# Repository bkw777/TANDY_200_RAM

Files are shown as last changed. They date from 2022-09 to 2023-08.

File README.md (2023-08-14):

# Option RAM module for TANDY 200

Replacements for TANDY 26-3866 24K SRAM module for TANDY 200 portable computer.

There are a few different options here. You pick whichever you need.  
* Single-bank, SOP-28 chip - Drop-in replacement for the original 24K module, with a large-ish chip that's relatively easy to solder by hand. Use this if you already have one original ceramic module, and want to keep using it, and just want one more 24K module to fill the machine, and you prefer to use, or happen to already have an SOIC-28/SOP-28 version of the SRAM chip.
* Single-bank, TSOP-28 chip - Same as above but uses a TSOP version of the SRAM chip.
* Dual-bank, SOP-32 chip - This provides the full 48 as 2 normal 24K modules all on one board. You plug a single one of these into OPTION RAM#2 slot. Uses an SOIC-32/SOP-32 chip for easier hand soldering.
* Dual-bank, TSOP-32 chip - Same as above but uses a TSOP version of the SRAM chip. These are more common and more available, but also more of a challenge to solder by hand.

The holes for the pins are intentionally too small to accept common square or round pins, as they are too fat and damage the leaf-style sockets in the 200. The BOMs include a specific pin that is extra thin, almost as thin as a dip chip leg. You may also use a SIL leadframe that has flat pins exactly like a DIP chip leg. See this [dip pcb legs guide](https://gist.github.com/bkw777/52d85d89eeff8445cc667685d05ea94d) for more details and links.

<!--
There are a few different designs available that all do the same thing but using different parts.

Some variants are single-bank like the original TANDY 26-3866 ceramic 24k module. These are drop-in replacements for the original modules, where one board = one bank = one Option RAM socket. You can have up to two boards installed in the machine.

Some variants are dual-bank, where one board supplies both Option RAM bank #1 and #2. You plug the one board into the Option RAM #2 socket, and this takes the place of two single-bank modules.

Some variants use different chip packages, so that you have options to use whatever types of chip you have, or can get, or can solder by hand.

There is also a [schematic of the original RAM bank](TANDY_26-3866.svg), re-drawn in KiCAD just for reference. There is no PCB for this, it's just for reference while designing new replacement modules to help ensure the replacement really still outwardly works the same as the original.
-->

See the [releases](../../releases) tab for gerber zips for manufacturing.  
If there is no link to order a pcb for one of the versions below, it means that design isn't tested and proven yet.

## Single-Bank - SOP

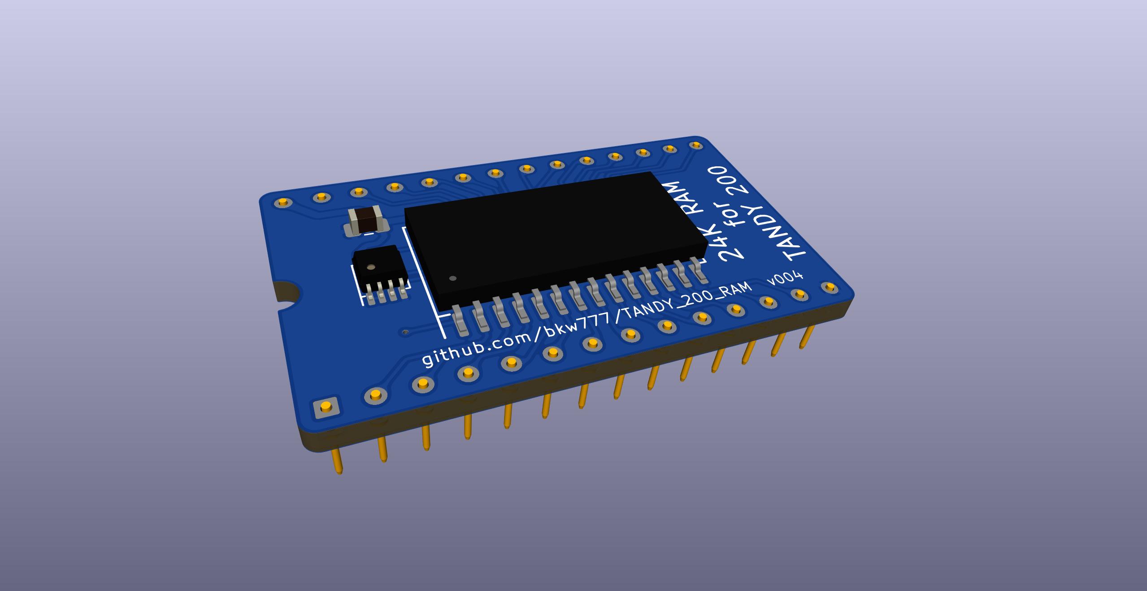
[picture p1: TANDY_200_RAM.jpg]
  
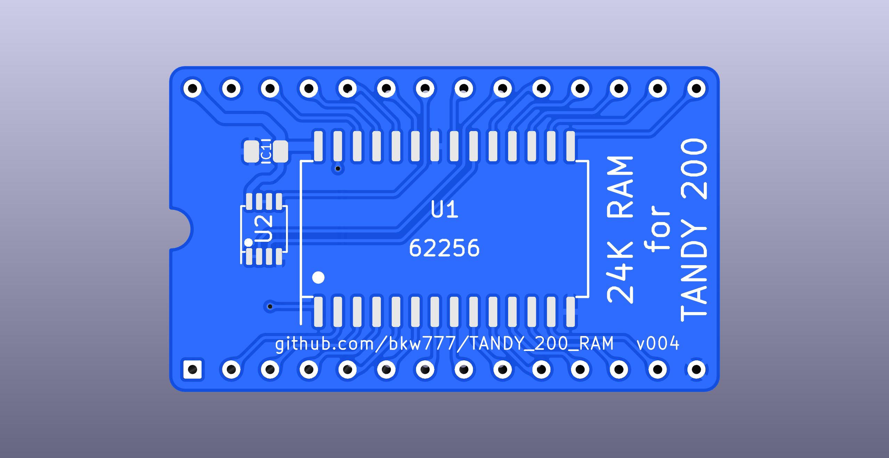
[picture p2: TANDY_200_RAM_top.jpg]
  
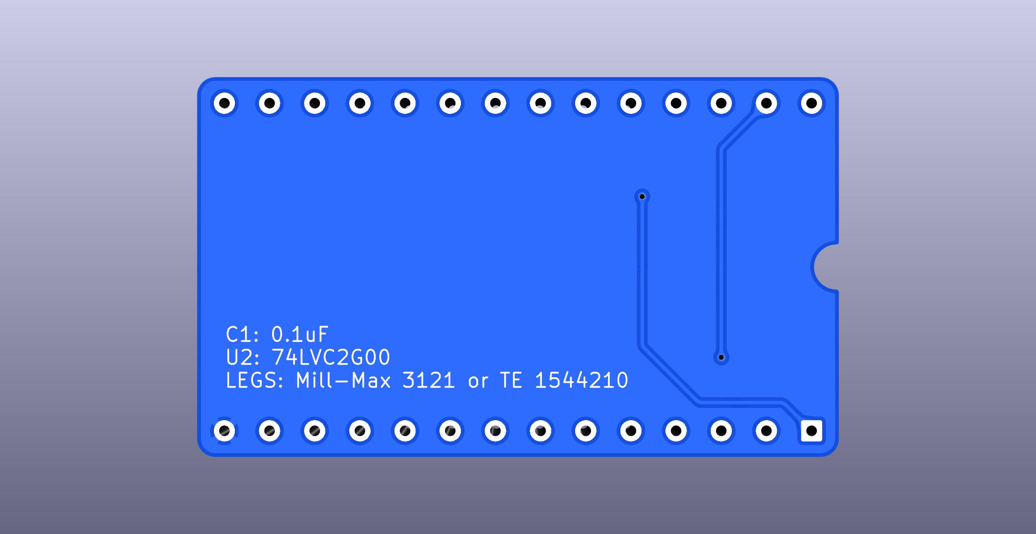
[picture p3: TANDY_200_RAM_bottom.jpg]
  
  

<!-- PCB from [OSHPark](),  or  [PCBWAY](),  or  [gerbers](../../releases/latest/)  -->
BOM from [DigiKey](https://www.digikey.com/short/f5hhwt4j),  or  [TANDY_200_RAM.BOM.csv](TANDY_200_RAM.BOM.csv)  

## Single-Bank - TSOP

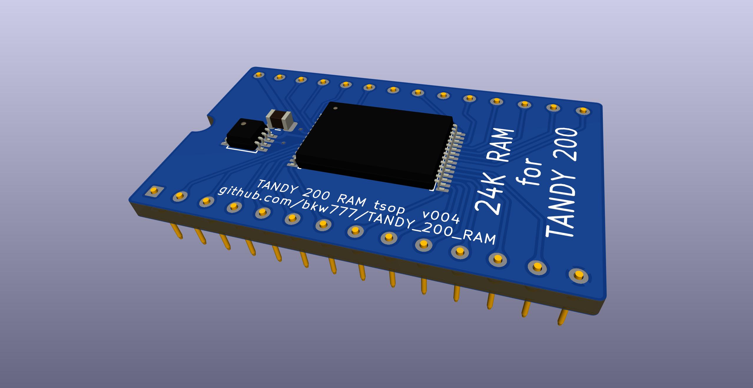
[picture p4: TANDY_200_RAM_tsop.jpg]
  
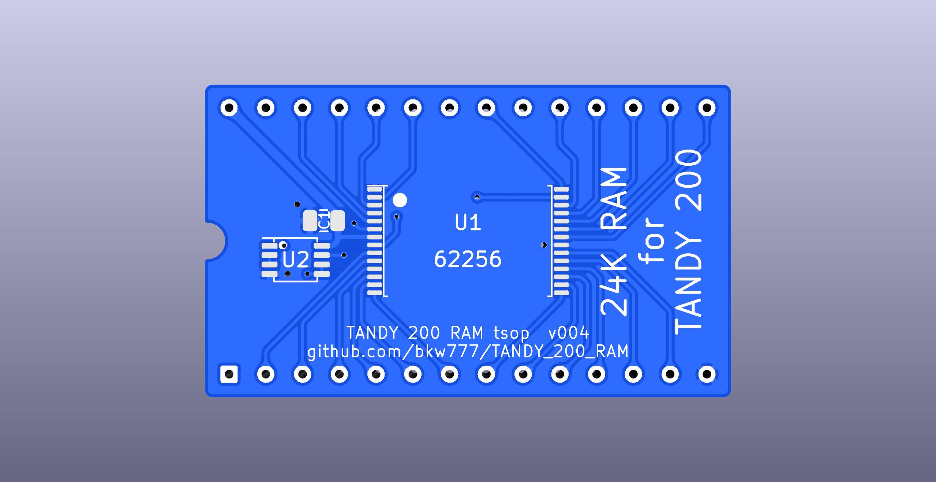
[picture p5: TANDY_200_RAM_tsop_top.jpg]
  
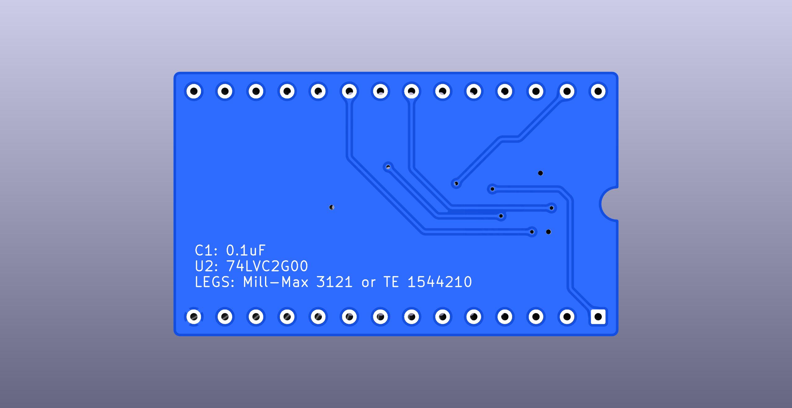
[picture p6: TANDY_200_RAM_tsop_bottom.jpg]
  

<!-- ![](../../raw/main/TANDY_200_RAM_tsop.svg)   -->

<!--
PCB from [OSHPark](),  or  [PCBWAY](),  or  [gerbers](../../releases/latest)  
BOM from [DigiKey](),  or  [BOM.csv]()  
-->

<!--
## Single-Bank THT DIP

![](../../raw/main/TANDY_200_RAM_tht.jpg)  
![](../../raw/main/TANDY_200_RAM_tht_top.jpg)  
![](../../raw/main/TANDY_200_RAM_tht_bottom.jpg)  
![](../../raw/main/TANDY_200_RAM_tht.svg)  

PCB from [OSHPark](),  or  [PCBWAY](),  or  [gerbers](../../releases/latest)  
BOM from [DigiKey](),  or  [BOM.csv]()  
-->

## Dual-Bank - SOP

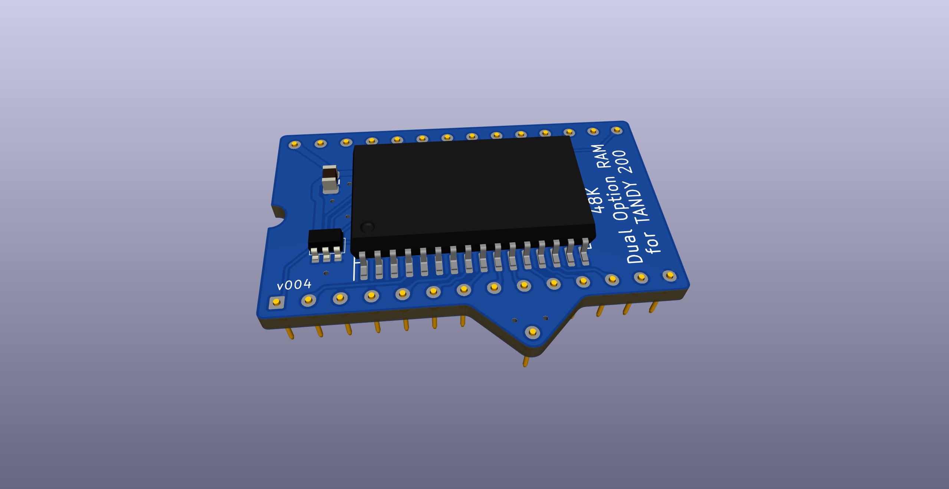
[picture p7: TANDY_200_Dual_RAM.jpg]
  
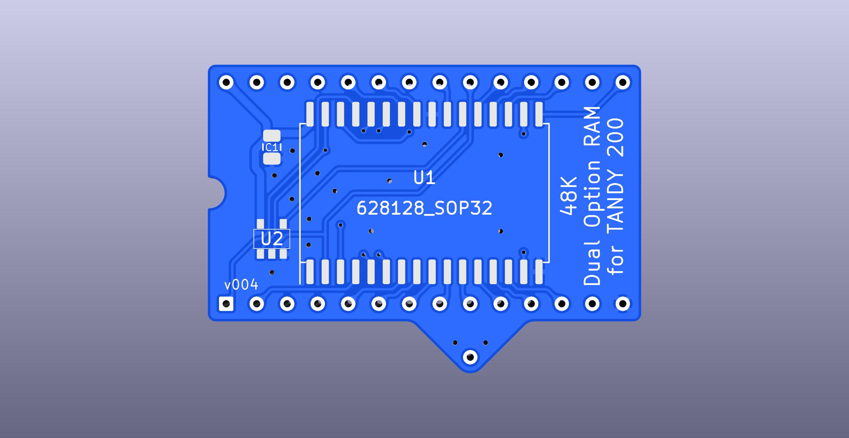
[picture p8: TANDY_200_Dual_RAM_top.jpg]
  
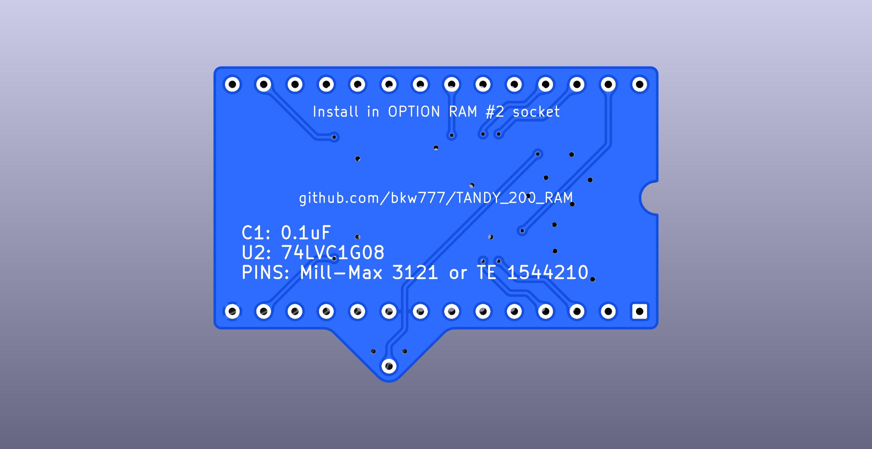
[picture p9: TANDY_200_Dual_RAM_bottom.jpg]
  
  

<!-- PCB from [OSHPark](),  or  [PCBWAY](),  or  [gerbers](../../releases/latest/)  -->  
BOM from [DigiKey](https://www.digikey.com/short/25v45c90),  or  [TANDY_200_Dual_RAM.BOM.csv](TANDY_200_Dual_RAM.BOM.csv)  

## Dual-Bank - TSOP

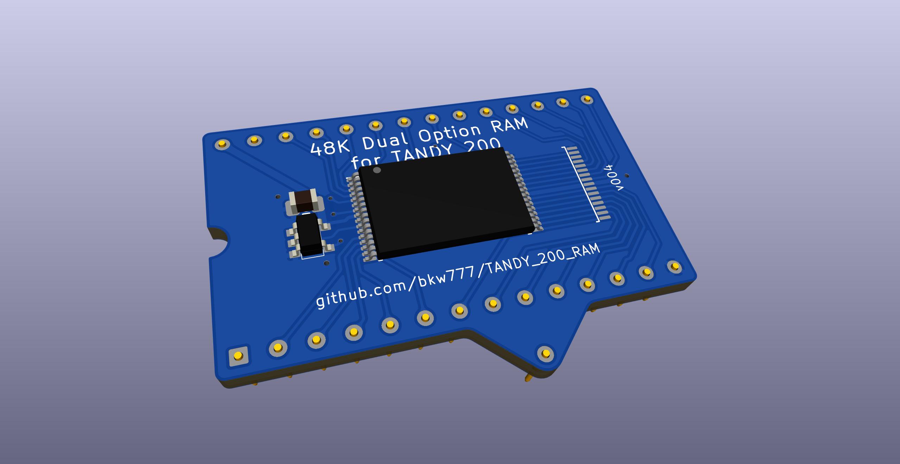
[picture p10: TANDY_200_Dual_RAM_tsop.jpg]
  
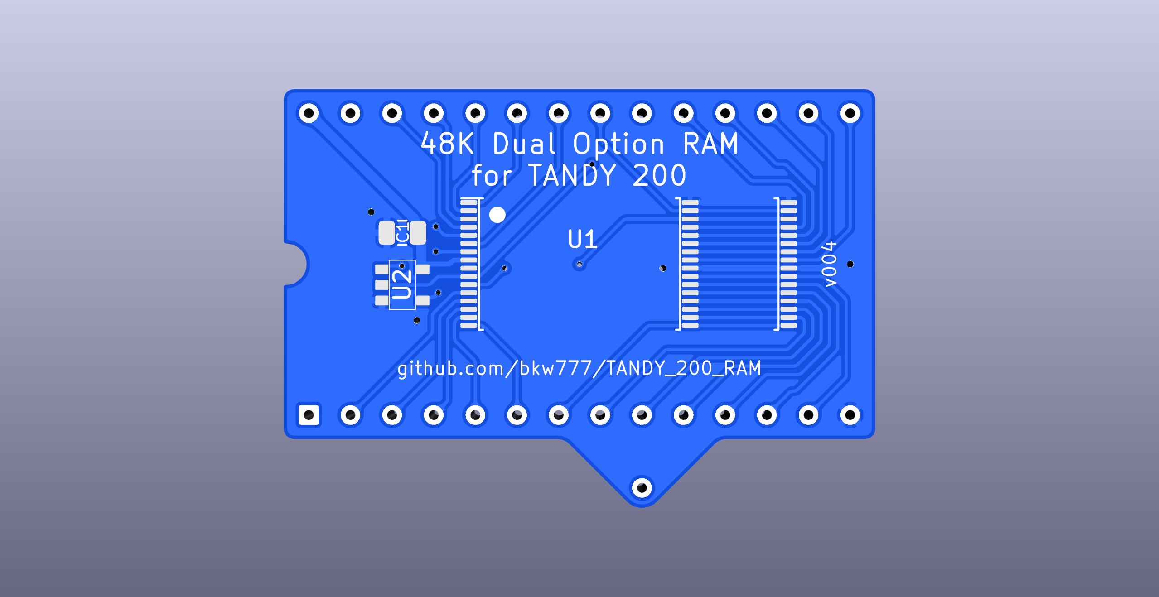
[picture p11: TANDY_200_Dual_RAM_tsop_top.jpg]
  
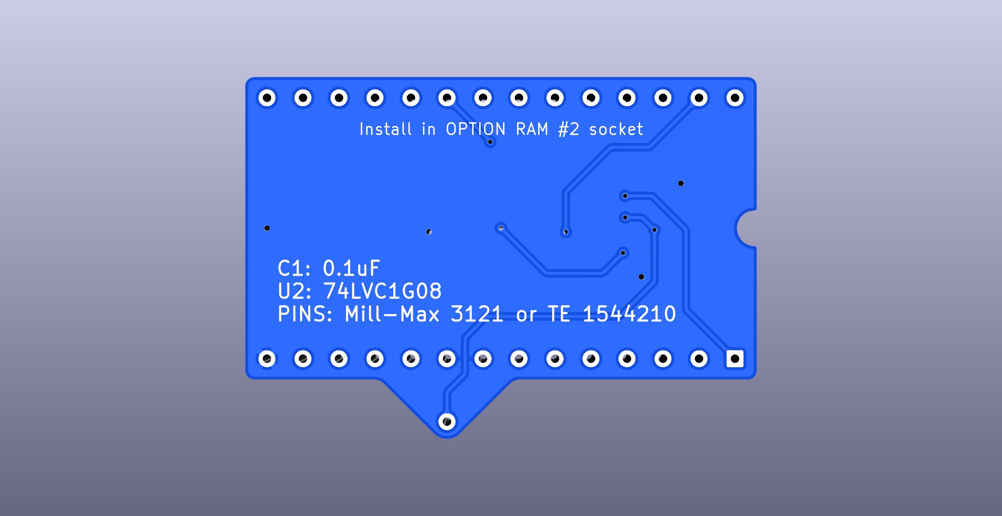
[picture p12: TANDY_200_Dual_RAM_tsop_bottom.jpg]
  
  

Supports both TSOP-32 (20mm) and sTSOP-32 (14mm).  

PCB from <!-- [OSHPark](),  or  -->[PCBWAY](https://www.pcbway.com/project/shareproject/TANDY_200_RAM_48K_TSOP_57aa6fd6.html),  or  [gerbers](../../releases/latest)  
BOM from [DigiKey](https://www.digikey.com/short/bvrwht5d),  or  [TANDY_200_Dual_RAM_tsop.BOM.csv](TANDY_200_Dual_RAM_tsop.BOM.csv)  

<!--
## Dual-Bank THT DIP

![](../../raw/main/TANDY_200_Dual_RAM_tht.jpg)  
![](../../raw/main/TANDY_200_Dual_RAM_tht_top.jpg)  
![](../../raw/main/TANDY_200_Dual_RAM_tht_bottom.jpg)  
![](../../raw/main/TANDY_200_Dual_RAM_tht.svg)  

PCB from [OSHPark](),  or  [PCBWAY](),  or  [gerbers](../../releases/latest)  
BOM from [DigiKey](),  or  [BOM.csv]()  
-->

## Original TANDY 26-3866 24K Option RAM for reference  
Re-drawn in KiCAD from the info in the service manual.  
This is what any alternative must replicate or emulate.  
The internal 24K bank is also the same (without the ceramic DIP carrier module).


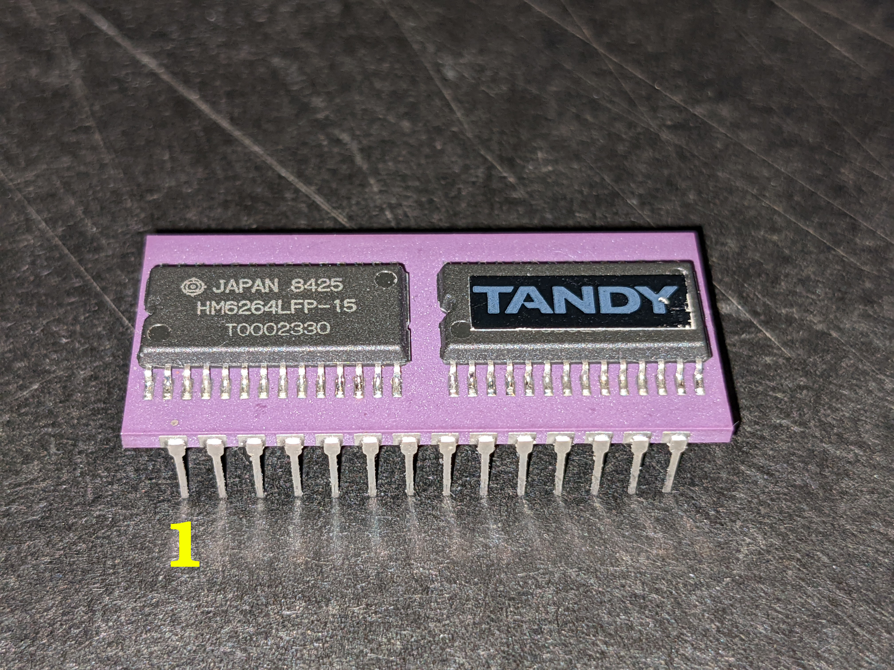
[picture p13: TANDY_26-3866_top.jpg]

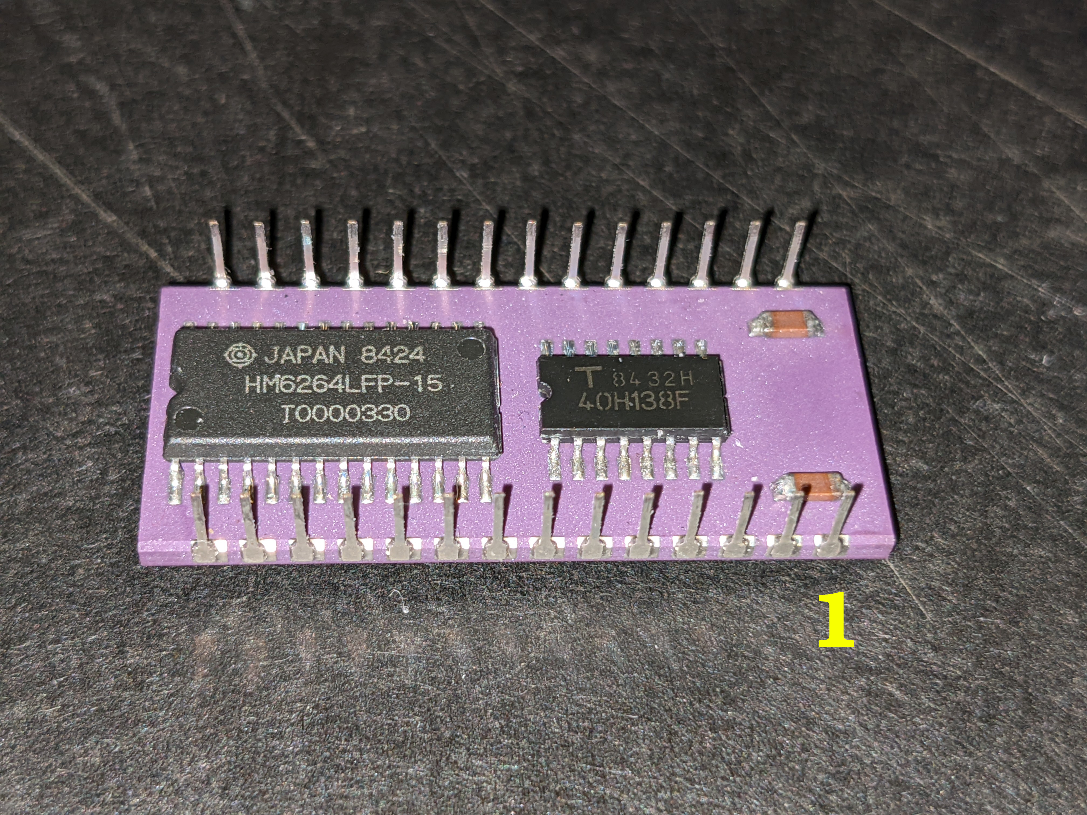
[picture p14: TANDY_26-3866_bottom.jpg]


## Misc Notes  
Memory Tester app for TANDY 200  
https://github.com/LivingM100SIG/Living_M100SIG/blob/main/M100SIG/Lib-10-TANDY200/MEMCHK.200  
https://github.com/LivingM100SIG/Living_M100SIG/blob/main/M100SIG/Lib-10-TANDY200/MEMCHK.SRC

The BOM includes Mill-Max 3121 machined brass micro pins, but there are a couple of other ways to make properly thin [PCB DIP legs](https://gist.github.com/bkw777/52d85d89eeff8445cc667685d05ea94d) .

The DIP row spacing is actually 725 mils not 700. This makes it a little bit annoying to solder the legs because the rows don't line up exactly with the 100-mil rows in a breadboard, but the odd spacing is deliberate not an arror.  

Suggestion for soldering the pins:  
Use some generic single-row female pin headers in a breadboard to hold the pins in alignment for soldering.  
Take 2 rows of 28 pins of single-row female pin headers and insert them into a breadboard 600 mils apart like for a normal 600 mil dip.  
One row is for holding pins, the other will not line up with the other row of holes, it is just for the pcb to rest on to hold up the other side of the pcb so it's level.  
Dip the post end of a pin in tacky solder paste, and insert into a hole in the pcb. Let the flux hold the pin in the pcb, don't worry about how loose the fit is and how the pin isn't held perfectly straight. Repeat for all 14 pins of ONE row of the pcb.
Insert the row of pins into one of the female sockets on the breadboard, laying the pcb across the top of the other socket. Solder the pins from the top.  
Extract the pcb from the socket and repeat for the other row of 14 pins. Finally do the single pin.  
The pins are very fragile. Be careful not to let them get bent, because they don't bend much before they break, and they bend easily, so just be real careful not to let anything catch on them and be careful when extracting from sockets not to allow the pcb to tip and angle.

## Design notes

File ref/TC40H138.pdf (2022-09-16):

This Material Copyrighted By Its Respective Manufacturer

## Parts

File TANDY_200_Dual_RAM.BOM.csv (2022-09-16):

Index | Quantity | Part Number | Manufacturer Part Number | Description | Customer Reference | Available | Backorder | Unit Price | Extended Price USD
1 | 1 | 732-8045-1-ND | 885012207045 | CAP CER 0.1UF 16V X7R 0805 |  | 1 | 0 | 0.10000 | 0.10
2 | 28 | ED1081-ND | 3121-2-00-15-00-00-08-0 | CONN PC PIN CIRC 0.017DIA GOLD |  | 28 | 0 | 0.11480 | 3.21
3 | 1 | 1727-4115-1-ND | 74LVC1G08GV,125 | IC GATE AND 1CH 2-INP SC74A |  | 1 | 0 | 0.38000 | 0.38
4 | 1 | 1450-1018-ND | AS6C1008-55SIN | IC SRAM 1MBIT PARALLEL 32SOP |  | 1 | 0 | 3.21000 | 3.21

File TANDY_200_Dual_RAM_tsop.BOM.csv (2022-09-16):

Index | Quantity | Part Number | Manufacturer Part Number | Description | Customer Reference | Available | Backorder | Unit Price | Extended Price USD
1 | 1 | 732-8045-1-ND | 885012207045 | CAP CER 0.1UF 16V X7R 0805 |  | 1 | 0 | 0.10000 | 0.10
2 | 29 | ED1081-ND | 3121-2-00-15-00-00-08-0 | CONN PC PIN CIRC 0.017DIA GOLD |  | 29 | 0 | 0.11480 | 3.33
3 | 1 | 1727-4115-1-ND | 74LVC1G08GV,125 | IC GATE AND 1CH 2-INP SC74A |  | 1 | 0 | 0.38000 | 0.38
4 | 1 | 1450-1019-ND | AS6C1008-55STIN | IC SRAM 1MBIT PARALLEL 32STSOP |  | 1 | 0 | 3.33000 | 3.33

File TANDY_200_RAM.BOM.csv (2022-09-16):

Index | Quantity | Part Number | Manufacturer Part Number | Description | Customer Reference | Available | Backorder | Unit Price | Extended Price USD
1 | 1 | 1450-1034-ND | AS6C62256-55SCN | IC SRAM 256KBIT PARALLEL 28SOP |  | 1 | 0 | 3.45000 | 3.45
2 | 1 | 1727-5985-1-ND | 74LVC2G00DP,125 | IC GATE NAND 2CH 2-INP 8TSSOP |  | 1 | 0 | 0.61000 | 0.61
3 | 1 | 732-8045-1-ND | 885012207045 | CAP CER 0.1UF 16V X7R 0805 |  | 1 | 0 | 0.10000 | 0.10
4 | 28 | ED1081-ND | 3121-2-00-15-00-00-08-0 | CONN PC PIN CIRC 0.017DIA GOLD |  | 28 | 0 | 0.11480 | 3.21

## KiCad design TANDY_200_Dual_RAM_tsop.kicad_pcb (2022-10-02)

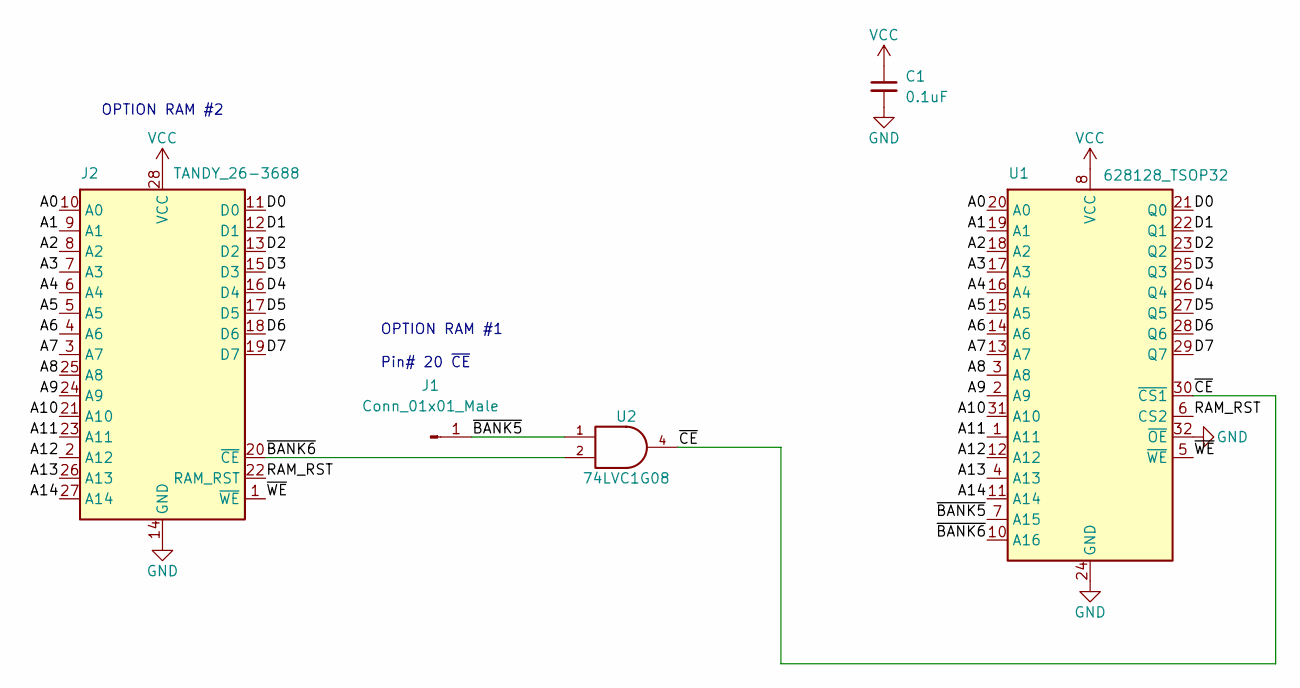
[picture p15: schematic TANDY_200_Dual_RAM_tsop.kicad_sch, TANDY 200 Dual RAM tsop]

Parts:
C1: 0.1uF; C_0805
J1: Conn_01x01_Male; Mill-Max 3121
J2: TANDY_26-3688; KEL ICC05-028-360TP
U1: 628128_TSOP32; TSOP32-dual
U2: 74LVC1G08; SOT-23-5

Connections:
/A0: J2.10 (A0), U1.20 (A0)
/A1: J2.9 (A1), U1.19 (A1)
/A2: J2.8 (A2), U1.18 (A2)
/A3: J2.7 (A3), U1.17 (A3)
/A4: J2.6 (A4), U1.16 (A4)
/A5: J2.5 (A5), U1.15 (A5)
/A6: J2.4 (A6), U1.14 (A6)
/A7: J2.3 (A7), U1.13 (A7)
/A8: J2.25 (A8), U1.3 (A8)
/A9: J2.24 (A9), U1.2 (A9)
/A10: J2.21 (A10), U1.31 (A10)
/A11: J2.23 (A11), U1.1 (A11)
/A12: J2.2 (A12), U1.12 (A12)
/A13: J2.26 (A13), U1.4 (A13)
/A14: J2.27 (A14), U1.11 (A14)
/D0: J2.11 (D0), U1.21 (Q0)
/D1: J2.12 (D1), U1.22 (Q1)
/D2: J2.13 (D2), U1.23 (Q2)
/D3: J2.15 (D3), U1.25 (Q3)
/D4: J2.16 (D4), U1.26 (Q4)
/D5: J2.17 (D5), U1.27 (Q5)
/D6: J2.18 (D6), U1.28 (Q6)
/D7: J2.19 (D7), U1.29 (Q7)
/RAM_RST: J2.22 (RAM_RST), U1.6 (CS2)
/~BANK5: J1.1, U1.7 (A15), U2.1
/~BANK6: J2.20 (~CE), U1.10 (A16), U2.2
/~CE: U1.30 (~CS1), U2.4
/~WE: J2.1 (~WE), U1.5 (~WE)
GND: C1.2, J2.14 (GND), U1.24 (GND), U1.32 (~OE), U2.3 (GND)
VCC: C1.1, J2.28 (VCC), U1.8 (VCC), U2.5 (VCC)

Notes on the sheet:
OPTION RAM #1 Pin# 20 ~{CE}
OPTION RAM #2

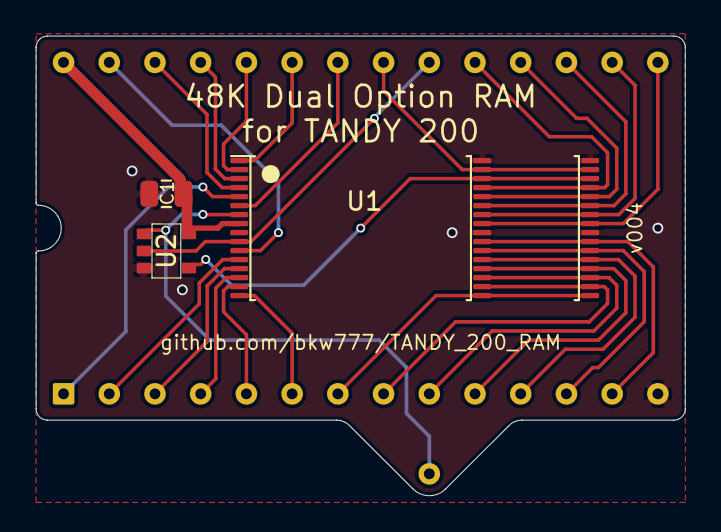
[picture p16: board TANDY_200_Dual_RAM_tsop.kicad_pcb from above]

Board: 2 copper layers, 36.1 x 25.5 mm, 5 parts (0 on the bottom side), 30 nets.

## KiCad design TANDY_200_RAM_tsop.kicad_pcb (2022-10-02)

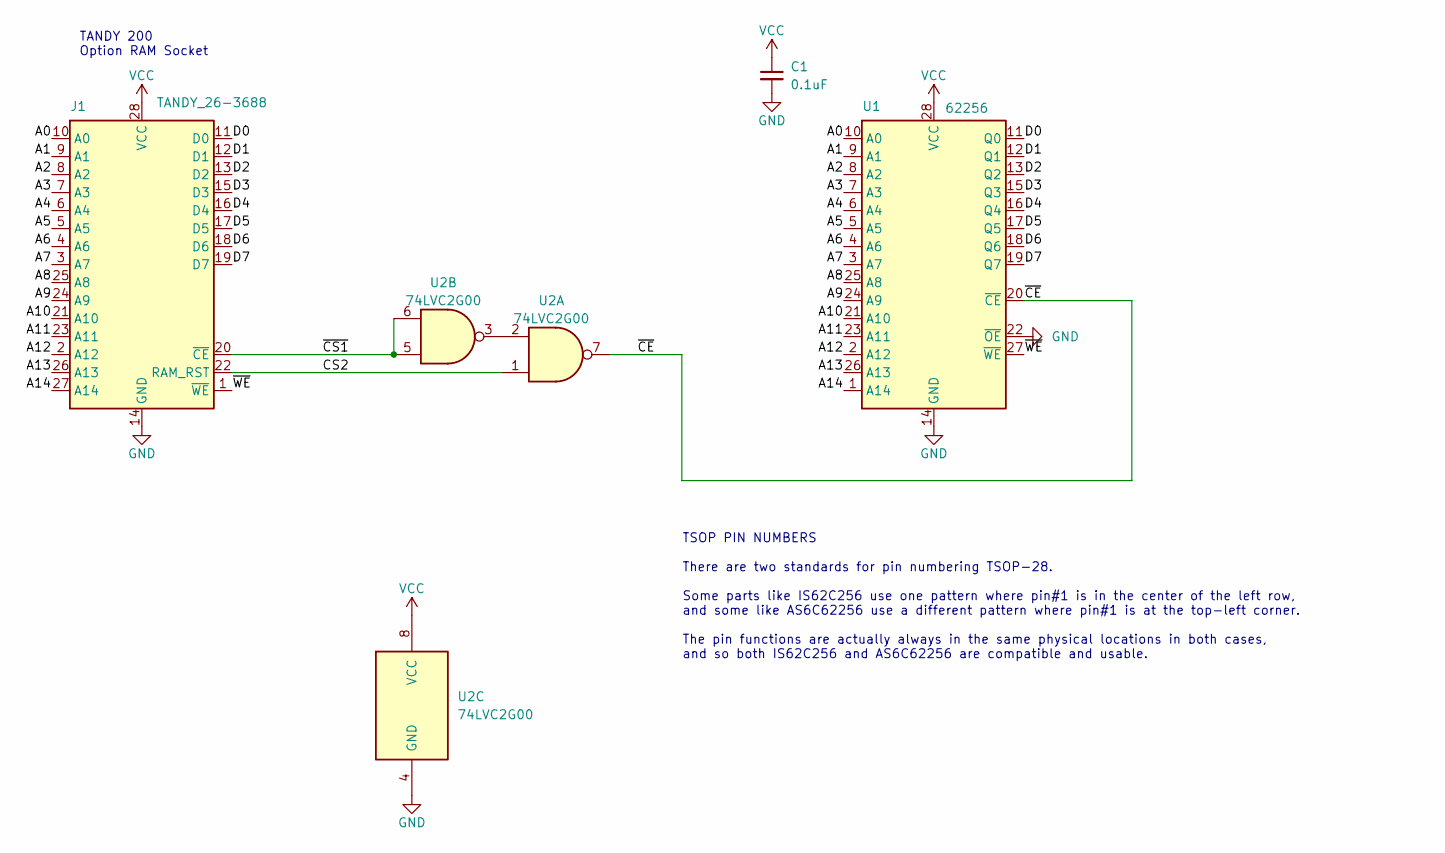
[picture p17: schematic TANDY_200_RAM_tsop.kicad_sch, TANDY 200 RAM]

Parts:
C1: 0.1uF; C_0805
J1: TANDY_26-3688; KEL ICC05-028-360TP
U1: 62256; TSOP-28
U2: 74LVC2G00; SSOP-8_2.95x2.8x0.65

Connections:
/A0: J1.10 (A0), U1.10 (A0)
/A1: J1.9 (A1), U1.9 (A1)
/A2: J1.8 (A2), U1.8 (A2)
/A3: J1.7 (A3), U1.7 (A3)
/A4: J1.6 (A4), U1.6 (A4)
/A5: J1.5 (A5), U1.5 (A5)
/A6: J1.4 (A6), U1.4 (A6)
/A7: J1.3 (A7), U1.3 (A7)
/A8: J1.25 (A8), U1.25 (A8)
/A9: J1.24 (A9), U1.24 (A9)
/A10: J1.21 (A10), U1.21 (A10)
/A11: J1.23 (A11), U1.23 (A11)
/A12: J1.2 (A12), U1.2 (A12)
/A13: J1.26 (A13), U1.26 (A13)
/A14: J1.27 (A14), U1.1 (A14)
/CS2: J1.22 (RAM_RST), U2.1
/D0: J1.11 (D0), U1.11 (Q0)
/D1: J1.12 (D1), U1.12 (Q1)
/D2: J1.13 (D2), U1.13 (Q2)
/D3: J1.15 (D3), U1.15 (Q3)
/D4: J1.16 (D4), U1.16 (Q4)
/D5: J1.17 (D5), U1.17 (Q5)
/D6: J1.18 (D6), U1.18 (Q6)
/D7: J1.19 (D7), U1.19 (Q7)
/~CE: U1.20 (~CE), U2.7
/~CS1: J1.20 (~CE), U2.5, U2.6
/~WE: J1.1 (~WE), U1.27 (~WE)
GND: C1.2, J1.14 (GND), U1.14 (GND), U1.22 (~OE), U2.4 (GND)
unnamed: U2.2, U2.3
VCC: C1.1, J1.28 (VCC), U1.28 (VCC), U2.8 (VCC)

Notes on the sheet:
TANDY 200 Option RAM Socket
TSOP PIN NUMBERS There are two standards for pin numbering TSOP-28. Some parts like IS62C256 use one pattern where pin#1 is in the center of the left row, and some like AS6C62256 use a different pattern where pin#1 is at the top-left corner. The pin functions are actually always in the same physica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

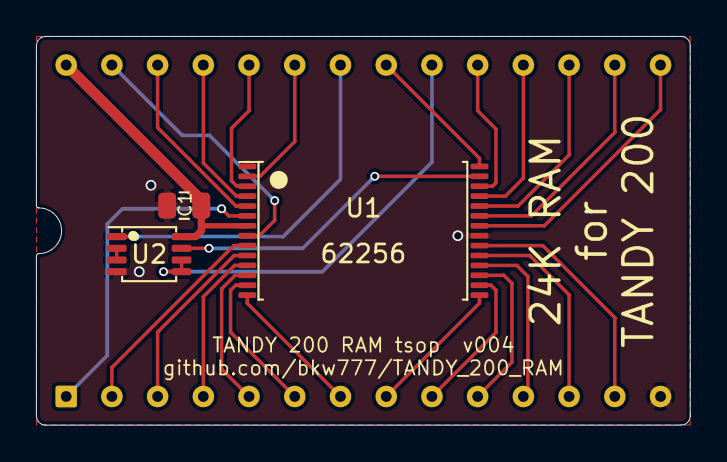
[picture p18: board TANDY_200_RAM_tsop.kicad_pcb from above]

Board: 2 copper layers, 36.3 x 21.6 mm, 4 parts (0 on the bottom side), 30 nets.

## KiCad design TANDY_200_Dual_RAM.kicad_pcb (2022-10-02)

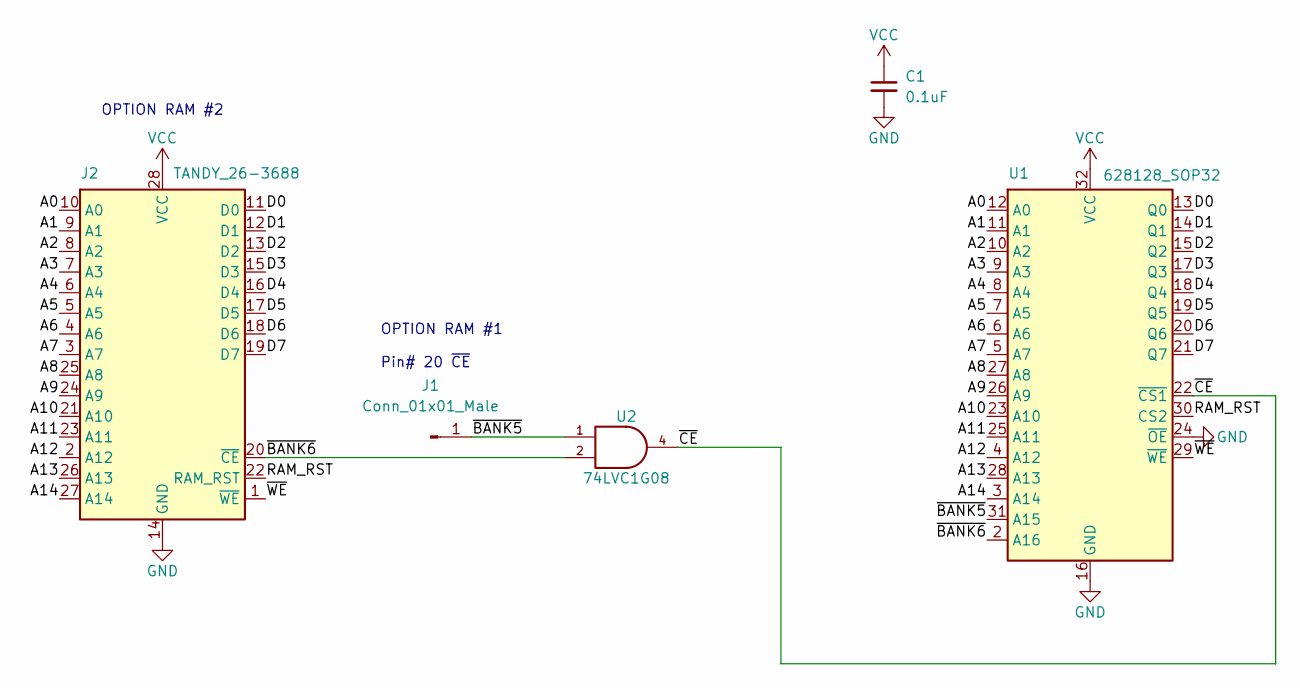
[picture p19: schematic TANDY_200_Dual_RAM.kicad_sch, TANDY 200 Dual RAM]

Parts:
C1: 0.1uF; C_0805
J1: Conn_01x01_Male; Mill-Max 3121
J2: TANDY_26-3688; KEL ICC05-028-360TP
U1: 628128_SOP32; SOP-32
U2: 74LVC1G08; SOT-23-5

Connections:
/A0: J2.10 (A0), U1.12 (A0)
/A1: J2.9 (A1), U1.11 (A1)
/A2: J2.8 (A2), U1.10 (A2)
/A3: J2.7 (A3), U1.9 (A3)
/A4: J2.6 (A4), U1.8 (A4)
/A5: J2.5 (A5), U1.7 (A5)
/A6: J2.4 (A6), U1.6 (A6)
/A7: J2.3 (A7), U1.5 (A7)
/A8: J2.25 (A8), U1.27 (A8)
/A9: J2.24 (A9), U1.26 (A9)
/A10: J2.21 (A10), U1.23 (A10)
/A11: J2.23 (A11), U1.25 (A11)
/A12: J2.2 (A12), U1.4 (A12)
/A13: J2.26 (A13), U1.28 (A13)
/A14: J2.27 (A14), U1.3 (A14)
/D0: J2.11 (D0), U1.13 (Q0)
/D1: J2.12 (D1), U1.14 (Q1)
/D2: J2.13 (D2), U1.15 (Q2)
/D3: J2.15 (D3), U1.17 (Q3)
/D4: J2.16 (D4), U1.18 (Q4)
/D5: J2.17 (D5), U1.19 (Q5)
/D6: J2.18 (D6), U1.20 (Q6)
/D7: J2.19 (D7), U1.21 (Q7)
/RAM_RST: J2.22 (RAM_RST), U1.30 (CS2)
/~BANK5: J1.1, U1.31 (A15), U2.1
/~BANK6: J2.20 (~CE), U1.2 (A16), U2.2
/~CE: U1.22 (~CS1), U2.4
/~WE: J2.1 (~WE), U1.29 (~WE)
GND: C1.2, J2.14 (GND), U1.16 (GND), U1.24 (~OE), U2.3 (GND)
VCC: C1.1, J2.28 (VCC), U1.32 (VCC), U2.5 (VCC)

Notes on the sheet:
OPTION RAM #1 Pin# 20 ~{CE}
OPTION RAM #2

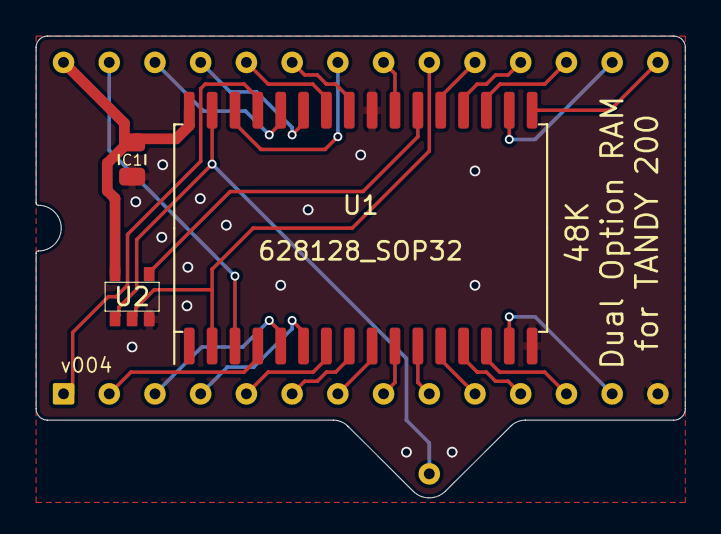
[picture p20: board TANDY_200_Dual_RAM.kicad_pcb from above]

Board: 2 copper layers, 36.1 x 25.7 mm, 5 parts (0 on the bottom side), 30 nets.

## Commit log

2022-09-16 ignore .kicad_prl
2022-09-16 add reference docs and project local library
    [TANDY_26-3866.kicad_sch]
2022-09-16 add boards: single-bank, dual-bank, dual-bank tsop
    [TANDY_200_Dual_RAM.BOM.csv, TANDY_200_Dual_RAM.kicad_pcb, TANDY_200_Dual_RAM.kicad_sch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]
2022-09-16 symmetrical part placement
    [TANDY_200_Dual_RAM.kicad_pcb]
2022-09-17 board outlines, ground planes
    [TANDY_200_Dual_RAM.kicad_pcb, TANDY_200_Dual_RAM_tsop.kicad_pcb, TANDY_200_RAM.kicad_pcb]
2022-09-17 schematic plot backgrounds
2022-09-19 add single-bank tsop
    [TANDY_200_Dual_RAM_tsop.kicad_pcb, TANDY_200_RAM.kicad_pcb, TANDY_200_RAM_tsop.kicad_pcb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]
2022-09-22 ground paths, footprints, sch symbols
    [TANDY_200_Dual_RAM.kicad_pcb, TANDY_200_Dual_RAM.kicad_sch, TANDY_200_Dual_RAM_tsop.kicad_pcb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]
2022-10-02 24k tsop layout and all board outlines expanded slightly
    [TANDY_200_Dual_RAM.kicad_pcb, TANDY_200_Dual_RAM_tsop.kicad_pcb, TANDY_200_RAM.kicad_pcb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]
2022-10-02 48k tsop ground pour
    [TANDY_200_Dual_RAM_tsop.kicad_pcb]
2022-10-04 readme, 48k tsop pcb link, pins soldering guide
